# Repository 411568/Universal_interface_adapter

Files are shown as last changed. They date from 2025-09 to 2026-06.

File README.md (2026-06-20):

# Universal Interface Adapter

> **One board. Every interface.**
>
> An open-source industrial communication and I/O platform for embedded development, automation, diagnostics, and rapid prototyping.

Board Image

---

# Universal Interface Adapter

The Universal Interface Adapter (UIA) is a compact, open-source hardware platform designed to bridge embedded systems with industrial and legacy communication interfaces.

Built around an STM32F446 microcontroller, the board combines communication buses, isolated digital inputs, relay outputs, MOSFET drivers, analog I/O, and general-purpose digital interfaces into a single development and integration platform.

Whether you're developing firmware, interfacing with industrial equipment, creating automated test fixtures, or experimenting with communication protocols, the Universal Interface Adapter provides all the essential interfaces on one board.

---

# Features

## Processing

* STM32F446VET6 ARM Cortex-M4 microcontroller
* Up to 180 MHz operation
* USB Full-Speed support
* Rich peripheral set for communication and control applications
* ST-Link programming and debugging interface

---

## Communication Interfaces

### CAN Bus

* Differential CAN transceiver
* Suitable for:

  * Automotive applications
  * Robotics
  * Industrial automation
  * Battery management systems
  * Motor controllers

### RS-232

* Legacy serial communication support
* Compatible with instrumentation and industrial equipment

### RS-422 / RS-485

* Differential long-distance communication
* Multi-drop network capability
* Industrial noise immunity
* Direction control handled by firmware

### UART

* Standard serial communication interface
* Ideal for microcontroller communication and debugging

### I²C

* Sensor and peripheral communication
* EEPROMs
* ADCs and DACs
* Environmental sensors

### SPI

* High-speed peripheral communication
* Displays
* Memory devices
* Data converters
* High-speed sensors

---

## Digital Inputs

### 3x Isolated Inputs

Galvanically isolated inputs designed for industrial environments.

Features:

* Ground loop protection
* Improved noise immunity
* Safe connection to external equipment
* PLC and sensor compatibility

Applications:

* Machine monitoring
* Industrial sensors
* Switch inputs
* Process control systems

---

## Output Interfaces

### 2x Relay Outputs

Integrated relay outputs for switching external devices.

Applications:

* Equipment control
* Power switching
* Automation systems
* Test fixtures
* Safety interlocks

---

### 4x MOSFET Outputs

Low-side MOSFET drivers for directly controlling external loads.

Applications:

* Solenoids
* LEDs
* Small motors
* Relays
* Indicators
* Custom automation systems

---

## General Purpose I/O

### 4x GPIO Channels

Flexible digital I/O for:

* External sensors
* Logic interfacing
* Prototyping
* Custom expansion hardware
* Embedded development

---

## Analog Interfaces

### Analog Inputs

Dedicated analog channels allow direct connection to sensors and measurement circuits.

Applications:

* Temperature sensors
* Voltage monitoring
* Current sensing
* Industrial transmitters
* Data acquisition

### Analog Output

Single analog output channel suitable for:

* Control signals
* Reference voltages
* External instrumentation
* Test equipment

---

## User Interface

### Status LEDs

Four onboard LEDs provide:

* System status indication
* Communication activity indicators
* Diagnostic information
* Application-defined signaling

---

## USB Connectivity

* USB Type-C connector
* USB Full-Speed device interface
* Virtual COM applications
* Firmware updates
* Data logging
* PC connectivity

---

# Hardware Architecture

The board is organized into dedicated functional blocks:

```
USB-C
   │
STM32F446VET6
   ├── CAN Interface
   ├── RS-232 Interface
   ├── RS-422 Interface
   ├── RS-485 Interface
   ├── UART Interfaces
   ├── I²C Interfaces
   ├── SPI Interfaces
   ├── Isolated Inputs
   ├── Relay Outputs
   ├── MOSFET Outputs
   ├── Analog Inputs
   ├── Analog Output
   ├── GPIO Expansion
   └── Status LEDs
```

---

# Firmware

The firmware is written in C and follows a modular architecture that separates hardware drivers from communication protocols and application logic.

## Firmware Responsibilities

### System Initialization

* Clock configuration
* Peripheral initialization
* Interface configuration
* Self-test routines

### Communication Services

* CAN message handling
* RS-232 communication
* RS-422 communication
* RS-485 communication
* USB communication
* UART bridging
* I²C transactions
* SPI transactions

### I/O Services

* Digital input monitoring
* Relay control
* MOSFET output control
* Analog acquisition
* GPIO management

### Application Layer

* Command parser
* Protocol routing
* Event handling
* Diagnostics
* Future protocol extensions

---

# Repository Structure

```
Universal_interface_adapter/
├── firmware/          Firmware source code
├── bom/               Bill of Materials
├── production/        Manufacturing files
├── libs/              Custom KiCad libraries
├── *.kicad_sch        Schematics
├── *.kicad_pcb        PCB layout
├── *.step             3D model
└── schematic_pdf.pdf  Complete schematic documentation
```

---

# Applications

## Industrial Automation

* PLC integration
* Factory diagnostics
* Equipment monitoring
* Protocol conversion

## Embedded Development

* Firmware development
* Hardware bring-up
* Peripheral testing
* Prototyping

## Automotive Development

* CAN experimentation
* ECU diagnostics
* Communication gateways

## Automated Test Systems

* Manufacturing fixtures
* Hardware-in-the-loop testing
* Sensor validation
* Production diagnostics

## Education

* Embedded systems laboratories
* Industrial communication training
* Electronics courses
* Protocol experimentation

---

# Open Hardware

This project is fully open source.

Included in this repository:

* Complete KiCad project
* Schematics
* PCB layout
* Manufacturing files
* Bill of Materials
* Firmware source code
* 3D STEP model

Users are encouraged to study, modify, and extend the design.

---

# Future Commercial Availability

The Universal Interface Adapter is currently under active development.

Planned future offerings:

* Fully assembled and tested boards
* Pre-programmed firmware
* Documentation and example projects
* PC configuration software
* Protocol bridge applications
* Optional enclosure kit
* Long-term firmware support

---

# Vision

The goal of the Universal Interface Adapter is simple:

**Provide developers and engineers with a single board capable of interfacing with nearly every common industrial and embedded communication standard without requiring multiple adapters or development platforms.**

**One board. Multiple protocols. Unlimited possibilities.**

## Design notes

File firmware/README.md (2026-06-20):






# Universal Interface Adapter Firmware

Firmware for the **Universal Interface Adapter (UIA)**, an open-source industrial communication and I/O platform built around the **STM32F446VET6** microcontroller.

The firmware is written entirely in **Rust** and follows a modular architecture designed for reliability, maintainability, and community-driven development.

---

# Philosophy

The goal of this firmware is simple:

> Make industrial and embedded interfaces easy to access, easy to understand, and easy to extend.

Every hardware feature on the board is exposed through a common command-line interface (CLI) over USB, making the board useful as:

* Development platform
* Hardware test tool
* Protocol analyzer
* Automation controller
* Educational platform
* Rapid prototyping tool

---

# Features

## USB CDC Command Interface

The board enumerates as a USB CDC-ACM serial device and provides an interactive CLI.

No special drivers are required on Linux and macOS. Windows typically uses the standard USB serial driver.

Example:

```text
$ screen /dev/ttyACM0 115200
UIA>
```

---

## Supported Interfaces

### Digital Outputs

* 4x MOSFET outputs
* 2x Relay outputs

### Digital Inputs

* 3x Isolated inputs
* 4x GPIO channels

### Analog Interfaces

* 2x Analog inputs (ADC)
* 1x Analog output (DAC)

### Serial Interfaces

* UART
* RS-232
* RS-422
* CAN
* I²C
* SPI

### User Interface

* 4x Status LEDs
* USB command interface

---

# Firmware Architecture

The firmware intentionally separates hardware initialization, drivers, and command handling.

```text
main.rs
│
├── Peripheral Initialization
│   ├── GPIO
│   ├── ADC / DAC
│   ├── UART
│   ├── RS232
│   ├── RS422
│   ├── I²C
│   ├── SPI
│   ├── CAN
│   └── USB
│
├── Command Registry
│   ├── LED Commands
│   ├── MOSFET Commands
│   ├── Relay Commands
│   ├── GPIO Commands
│   ├── Analog Commands
│   ├── Serial Commands
│   └── Interface Commands
│
└── CLI Event Loop
```

The command registry allows new functionality to be added without modifying the main application loop.

---

# Project Structure

```text
firmware/
├── src/
│   ├── main.rs
│   ├── cli/
│   │   ├── mod.rs
│   │   └── commands/
│   └── io_interface/
├── Cargo.toml
├── memory.x
└── README.md
```

---

# Current Command Modules

The firmware currently implements command handlers for:

* Echo
* Setup
* LEDs
* MOSFET outputs
* Relays
* Isolated inputs
* GPIO
* UART
* RS-232
* RS-422
* Analog I/O
* I²C
* SPI
* CAN

Each module is responsible for:

1. Hardware initialization
2. Runtime control
3. CLI integration
4. Error handling

---

# Building

## Requirements

* Rust stable toolchain
* rustup
* cargo
* ARM target support

Install the target:

```bash
rustup target add thumbv7em-none-eabihf
```

---

## Build

```bash
cargo build --release
```

---

## Flash

Example using probe-rs:

```bash
cargo install probe-rs-tools

probe-rs download \
    --chip STM32F446VETx \
    target/thumbv7em-none-eabihf/release/universal_interface_adapter
```

---

# Example CLI Usage

```text
UIA> led on 1
UIA> relay on 2
UIA> mosfet off 3
UIA> gpio read 1
UIA> adc read 0
UIA> i2c scan
UIA> can send 123 DEADBEEF
```

---

# Adding New Commands

The firmware was intentionally designed to make adding features straightforward.

Typical steps:

### 1. Create a command

```rust
pub struct MyCommand;

impl MyCommand {
    pub fn new() -> Self {
        Self
    }
}
```

### 2. Implement the command trait

```rust
impl Command for MyCommand {
    // implementation
}
```

### 3. Register the command

```rust
let _ = registry.register_my_command(MyCommand::new());
```

That's it. The CLI automatically exposes the new functionality.

---

# Why Rust?

Industrial and embedded systems often run continuously and interact with external hardware. Rust provides several advantages:

* Memory safety without garbage collection
* Strong type checking
* Zero-cost abstractions
* Excellent concurrency primitives
* Reduced risk of crashes and undefined behavior
* Maintainable long-term codebase

The objective is to build firmware that is both reliable enough for industrial use and approachable enough for experimentation and learning.

---

# Contributing

Contributions are highly encouraged.

Ideas for future improvements:

* Additional CLI commands
* Protocol bridges
* Configuration storage
* Data logging
* Scriptable command execution
* USB firmware update support
* Modbus support
* CANopen support
* MQTT gateway functionality
* Performance improvements
* Documentation improvements

Pull requests of all sizes are welcome.

If you have an idea, open an issue and let's discuss it.

---

# Development Principles

Please try to keep contributions:

* Modular
* Well documented
* Hardware independent where possible
* Non-blocking
* Safe and idiomatic Rust
* Easy to test and review

---

# Community

This project exists because embedded and industrial development tools should be open, understandable, and hackable.

If you build something interesting with the Universal Interface Adapter, improve the firmware, or add support for new protocols, please submit a pull request.

**Let's build a universal embedded interface platform together.**

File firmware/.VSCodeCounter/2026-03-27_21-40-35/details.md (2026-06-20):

# Details

Date : 2026-03-27 21:40:35

Directory /home/krzysztof/Documents/ELECTRONICS/universal_interface_adapter_board/universal_interface_adapter/firmware

Total : 25 files,  4782 codes, 385 comments, 669 blanks, all 5836 lines

[Summary](results.md) / Details / [Diff Summary](diff.md) / [Diff Details](diff-details.md)

## Files
| filename | language | code | comment | blank | total |
| :--- | :--- | ---: | ---: | ---: | ---: |
| [README.md](/README.md) | Markdown | 45 | 0 | 21 | 66 |
| [build.rs](/build.rs) | Rust | 2 | 0 | 4 | 6 |
| [src/cli/cli\_config.rs](/src/cli/cli_config.rs) | Rust | 69 | 19 | 15 | 103 |
| [src/cli/cli\_loop.rs](/src/cli/cli_loop.rs) | Rust | 99 | 19 | 15 | 133 |
| [src/cli/command.rs](/src/cli/command.rs) | Rust | 9 | 11 | 5 | 25 |
| [src/cli/commands/analog.rs](/src/cli/commands/analog.rs) | Rust | 476 | 27 | 61 | 564 |
| [src/cli/commands/can.rs](/src/cli/commands/can.rs) | Rust | 485 | 26 | 65 | 576 |
| [src/cli/commands/clear.rs](/src/cli/commands/clear.rs) | Rust | 29 | 9 | 9 | 47 |
| [src/cli/commands/echo.rs](/src/cli/commands/echo.rs) | Rust | 48 | 10 | 8 | 66 |
| [src/cli/commands/gpios.rs](/src/cli/commands/gpios.rs) | Rust | 297 | 31 | 39 | 367 |
| [src/cli/commands/i2c.rs](/src/cli/commands/i2c.rs) | Rust | 447 | 16 | 51 | 514 |
| [src/cli/commands/isolated\_inputs.rs](/src/cli/commands/isolated_inputs.rs) | Rust | 120 | 8 | 17 | 145 |
| [src/cli/commands/led.rs](/src/cli/commands/led.rs) | Rust | 141 | 10 | 19 | 170 |
| [src/cli/commands/mod.rs](/src/cli/commands/mod.rs) | Rust | 220 | 65 | 47 | 332 |
| [src/cli/commands/mosfets.rs](/src/cli/commands/mosfets.rs) | Rust | 141 | 10 | 19 | 170 |
| [src/cli/commands/relays.rs](/src/cli/commands/relays.rs) | Rust | 129 | 10 | 19 | 158 |
| [src/cli/commands/rs232.rs](/src/cli/commands/rs232.rs) | Rust | 282 | 2 | 32 | 316 |
| [src/cli/commands/rs422.rs](/src/cli/commands/rs422.rs) | Rust | 322 | 8 | 37 | 367 |
| [src/cli/commands/setup.rs](/src/cli/commands/setup.rs) | Rust | 120 | 15 | 15 | 150 |
| [src/cli/commands/spi.rs](/src/cli/commands/spi.rs) | Rust | 620 | 27 | 72 | 719 |
| [src/cli/commands/uart.rs](/src/cli/commands/uart.rs) | Rust | 397 | 14 | 42 | 453 |
| [src/cli/mod.rs](/src/cli/mod.rs) | Rust | 8 | 0 | 2 | 10 |
| [src/io\_interface/mod.rs](/src/io_interface/mod.rs) | Rust | 1 | 0 | 0 | 1 |
| [src/io\_interface/serial.rs](/src/io_interface/serial.rs) | Rust | 72 | 14 | 13 | 99 |
| [src/main.rs](/src/main.rs) | Rust | 203 | 34 | 42 | 279 |

[Summary](results.md) / Details / [Diff Summary](diff.md) / [Diff Details](diff-details.md)

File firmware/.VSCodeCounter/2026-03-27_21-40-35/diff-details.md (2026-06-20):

# Diff Details

Date : 2026-03-27 21:40:35

Directory /home/krzysztof/Documents/ELECTRONICS/universal_interface_adapter_board/universal_interface_adapter/firmware

Total : 6 files,  2120 codes, 103 comments, 262 blanks, all 2485 lines

[Summary](results.md) / [Details](details.md) / [Diff Summary](diff.md) / Diff Details

## Files
| filename | language | code | comment | blank | total |
| :--- | :--- | ---: | ---: | ---: | ---: |
| [src/cli/commands/analog.rs](/src/cli/commands/analog.rs) | Rust | 476 | 27 | 61 | 564 |
| [src/cli/commands/can.rs](/src/cli/commands/can.rs) | Rust | 485 | 26 | 65 | 576 |
| [src/cli/commands/i2c.rs](/src/cli/commands/i2c.rs) | Rust | 447 | 16 | 51 | 514 |
| [src/cli/commands/mod.rs](/src/cli/commands/mod.rs) | Rust | 25 | 0 | 4 | 29 |
| [src/cli/commands/spi.rs](/src/cli/commands/spi.rs) | Rust | 620 | 27 | 72 | 719 |
| [src/main.rs](/src/main.rs) | Rust | 67 | 7 | 9 | 83 |

[Summary](results.md) / [Details](details.md) / [Diff Summary](diff.md) / Diff Details

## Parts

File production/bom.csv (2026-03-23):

Designator | Footprint | Quantity | Value | LCSC Part #
C1, C2 | 0603 | 2 | 20p
C10, C12 | 1206 | 2 | 2.2u
C11, C13, C15, C16, C17, C18, C3, C41, C5, C6, C7, C9 | 1206 | 12 | 100n
C14 | 1206 | 1 | 1u
C19, C20, C57, C58 | 0805 | 4 | 1u
C21, C24, C25, C26, C28, C29, C30, C31, C34, C35, C36, C37, C38, C39, C8 | 0805 | 15 | 100n
C22, C23, C33 | 0805 | 3 | 10u
C27, C32, C42 | 0805 | 3 | 10n
C4 | 1206 | 1 | 4.7u
C40, C43, C44, C45, C46, C47, C48 | 1206 | 7 | 10u
C49, C50, C51, C52 | 1206 | 4 | 22u
C53, C54, C55, C56 | 0805 | 4 | 22u
D1, D10, D13, D2, D7, D8 | 0805 | 6 | LED_RED
D11, D12, D14, D15, D29, D3, D30, D4, D5, D6, D9 | D_SMA_Handsoldering | 11 | D
D16 | 0805 | 1 | LED_ORANGE
D17 | 0805 | 1 | LED_YELLOW
D18 | 0805 | 1 | LED_GREEN
D19, D20, D21, D22, D23, D24, D25, D26, D27, D28 | D_SMA_Handsoldering | 10 | D_TVS_Small
D31 | D_SMA_Handsoldering | 1 | 35V TVS
D32, D33, D34, D35 | 0805 | 4 | LED GREEN
F1, F2, F3 | 1812 | 3 | RF1406-000
H1, H2, H3, H4 | MountingHole_3mm | 4 | MountingHole
IC1 | SOIC127P1032X265-20N | 1 | ADM3251EARWZ-REEL
J1 | PinHeader_1x08_P2.54mm_Horizontal | 1 | Conn_01x08_Male
J10, J12, J23, J27, J28, J9 | PhoenixContact_MC_1,5_2-G-3.5_1x02_P3.50mm_Horizontal | 6 | Phoenix
J11, J24, J25, J26, J7, J8 | PinHeader_1x02_P2.54mm_Vertical | 6 | Goldpin
J13, J15, J31, J33, J34 | PhoenixContact_MC_1,5_4-G-3.5_1x04_P3.50mm_Horizontal | 5 | Phoenix
J14, J16, J32, J39, J40 | PinHeader_1x04_P2.54mm_Vertical | 5 | Goldpin
J17, J19, J3, J35, J36, J4, J41, J42 | PhoenixContact_MC_1,5_3-G-3.5_1x03_P3.50mm_Horizontal | 8 | Phoenix
J18, J21, J37, J38, J43, J44, J5, J6 | PinHeader_1x03_P2.54mm_Vertical | 8 | Goldpin
J2 | GCT_USB4800-03-A_REVA | 1 | USB4800-03-A_REVA
J20 | PhoenixContact_MC_1,5_5-G-3.5_1x05_P3.50mm_Horizontal | 1 | Phoenix
J22 | PinHeader_1x05_P2.54mm_Vertical | 1 | Goldpin
J29 | PhoenixContact_MC_1,5_2-G-3.5_1x02_P3.50mm_Horizontal | 1 | Conn_01x02
J30 | BarrelJack_GCT_DCJ200-10-A_Horizontal | 1 | Barrel_Jack_Switch
JP1, JP10, JP11, JP12, JP13, JP14, JP15, JP16, JP17, JP18, JP19, JP2, JP20, JP21, JP22, JP3, JP4, JP8, JP9 | PinHeader_1x02_P2.54mm_Vertical | 19 | Jumper
JP5 | PinHeader_1x02_P2.54mm_Vertical | 1 | HS
JP6 | PinHeader_1x02_P2.54mm_Vertical | 1 | LP
JP7 | PinHeader_1x02_P2.54mm_Vertical | 1 | SC
K1, K2 | RELAY_LEG-24 | 2 | LEG-5
Q1, Q2, Q3, Q4, Q5, Q6 | SOT-23 | 6 | IRLML6244
R1, R5, R6 | 1206 | 3 | DNP
R10 | 1206 | 1 | 33k
R11 | 1206 | 1 | 82k
R12, R13, R29, R32, R33, R34, R35 | 0805 | 7 | 1k
R14, R15, R24, R25, R28, R42, R43, R46, R47, R74, R75, R76, R77 | 0805 | 13 | 2.2k
R16, R17, R20, R21, R22, R23, R30, R36, R37, R38, R39, R52, R58, R62, R64, R68, R69, R72, R73 | 0805 | 19 | 10k
R18, R19 | 0805 | 2 | 4.7k
R2, R3 | 1206 | 2 | 20
R26, R27, R31 | 0805 | 3 | 200
R4, R7 | 1206 | 2 | 5.1k
R40, R41, R44, R45 | 0805 | 4 | 100
R48 | 1206 | 1 | 47k
R49, R57 | 1206 | 2 | 120
R50, R51, R53, R54, R79, R80, R81, R82, R83, R84, R85, R86 | 0805 | 12 | 10
R55, R56 | 1206 | 2 | 560
R59 | 0805 | 1 | 30k
R60 | 0805 | 1 | 15k
R61 | 0805 | 1 | 0
R63, R65 | 0805 | 2 | 1.5k
R66, R67 | 0805 | 2 | 3.3k
R70 | 0805 | 1 | 1.37k
R71 | 0805 | 1 | 2.21k
R8, R9 | 1206 | 2 | 10k
SW1 | SW_SPST_TL3342 | 1 | SW_Push
U1 | SOT-23-6 | 1 | USBLC6-2SC6
U10, U11 | CONV_RPX-2.5-R | 2 | RPX-2.5-R
U12 | Converter_DCDC_TRACO_TEA1-xxxx_THT | 1 | TEA1-0505
U2 | LQFP-100_14x14mm_P0.5mm | 1 | STM32F446VETx
U3, U4, U5 | SO-4_4.4x3.6mm_P2.54mm | 3 | LTV-356T
U6 | SOIC-8_3.9x4.9mm_P1.27mm | 1 | SN65HVD230
U7 | VSSOP-8_2.3x2mm_P0.5mm | 1 | TXB0102DCU
U8 | SOIC-20W_7.5x12.8mm_P1.27mm | 1 | ADM2582E
U9 | SOIC-8_3.9x4.9mm_P1.27mm | 1 | OPA197xD
Y1 | Crystal_SMD_HC49-SD | 1 | 8MHz

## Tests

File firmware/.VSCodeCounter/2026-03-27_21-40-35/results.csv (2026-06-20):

filename | "language" | "Rust" | "Markdown" | "comment" | "blank" | "total"
/home/krzysztof/Documents/ELECTRONICS/universal_interface_adapter_board/universal_interface_adapter/firmware/README.md | "Markdown" | 0 | 45 | 0 | 21 | 66
/home/krzysztof/Documents/ELECTRONICS/universal_interface_adapter_board/universal_interface_adapter/firmware/build.rs | "Rust" | 2 | 0 | 0 | 4 | 6
/home/krzysztof/Documents/ELECTRONICS/universal_interface_adapter_board/universal_interface_adapter/firmware/src/cli/cli_config.rs | "Rust" | 69 | 0 | 19 | 15 | 103
/home/krzysztof/Documents/ELECTRONICS/universal_interface_adapter_board/universal_interface_adapter/firmware/src/cli/cli_loop.rs | "Rust" | 99 | 0 | 19 | 15 | 133
/home/krzysztof/Documents/ELECTRONICS/universal_interface_adapter_board/universal_interface_adapter/firmware/src/cli/command.rs | "Rust" | 9 | 0 | 11 | 5 | 25
/home/krzysztof/Documents/ELECTRONICS/universal_interface_adapter_board/universal_interface_adapter/firmware/src/cli/commands/analog.rs | "Rust" | 476 | 0 | 27 | 61 | 564
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

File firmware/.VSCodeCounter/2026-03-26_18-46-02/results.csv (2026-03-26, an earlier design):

filename | "language" | "Rust" | "Markdown" | "comment" | "blank" | "total"
/home/krzysztof/Documents/ELECTRONICS/universal_interface_adapter_board/universal_interface_adapter/firmware/README.md | "Markdown" | 0 | 45 | 0 | 21 | 66
/home/krzysztof/Documents/ELECTRONICS/universal_interface_adapter_board/universal_interface_adapter/firmware/build.rs | "Rust" | 2 | 0 | 0 | 4 | 6
/home/krzysztof/Documents/ELECTRONICS/universal_interface_adapter_board/universal_interface_adapter/firmware/src/cli/cli_config.rs | "Rust" | 69 | 0 | 19 | 15 | 103
/home/krzysztof/Documents/ELECTRONICS/universal_interface_adapter_board/universal_interface_adapter/firmware/src/cli/cli_loop.rs | "Rust" | 99 | 0 | 19 | 15 | 133
/home/krzysztof/Documents/ELECTRONICS/universal_interface_adapter_board/universal_interface_adapter/firmware/src/cli/command.rs | "Rust" | 9 | 0 | 11 | 5 | 25
/home/krzysztof/Documents/ELECTRONICS/universal_interface_adapter_board/universal_interface_adapter/firmware/src/cli/commands/clear.rs | "Rust" | 29 | 0 | 9 | 9 | 47
/home/krzysztof/Documents/ELECTRONICS/universal_interface_adapter_board/universal_interface_adapter/firmware/src/cli/commands/echo.rs | "Rust" | 48 | 0 | 10 | 8 | 66
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

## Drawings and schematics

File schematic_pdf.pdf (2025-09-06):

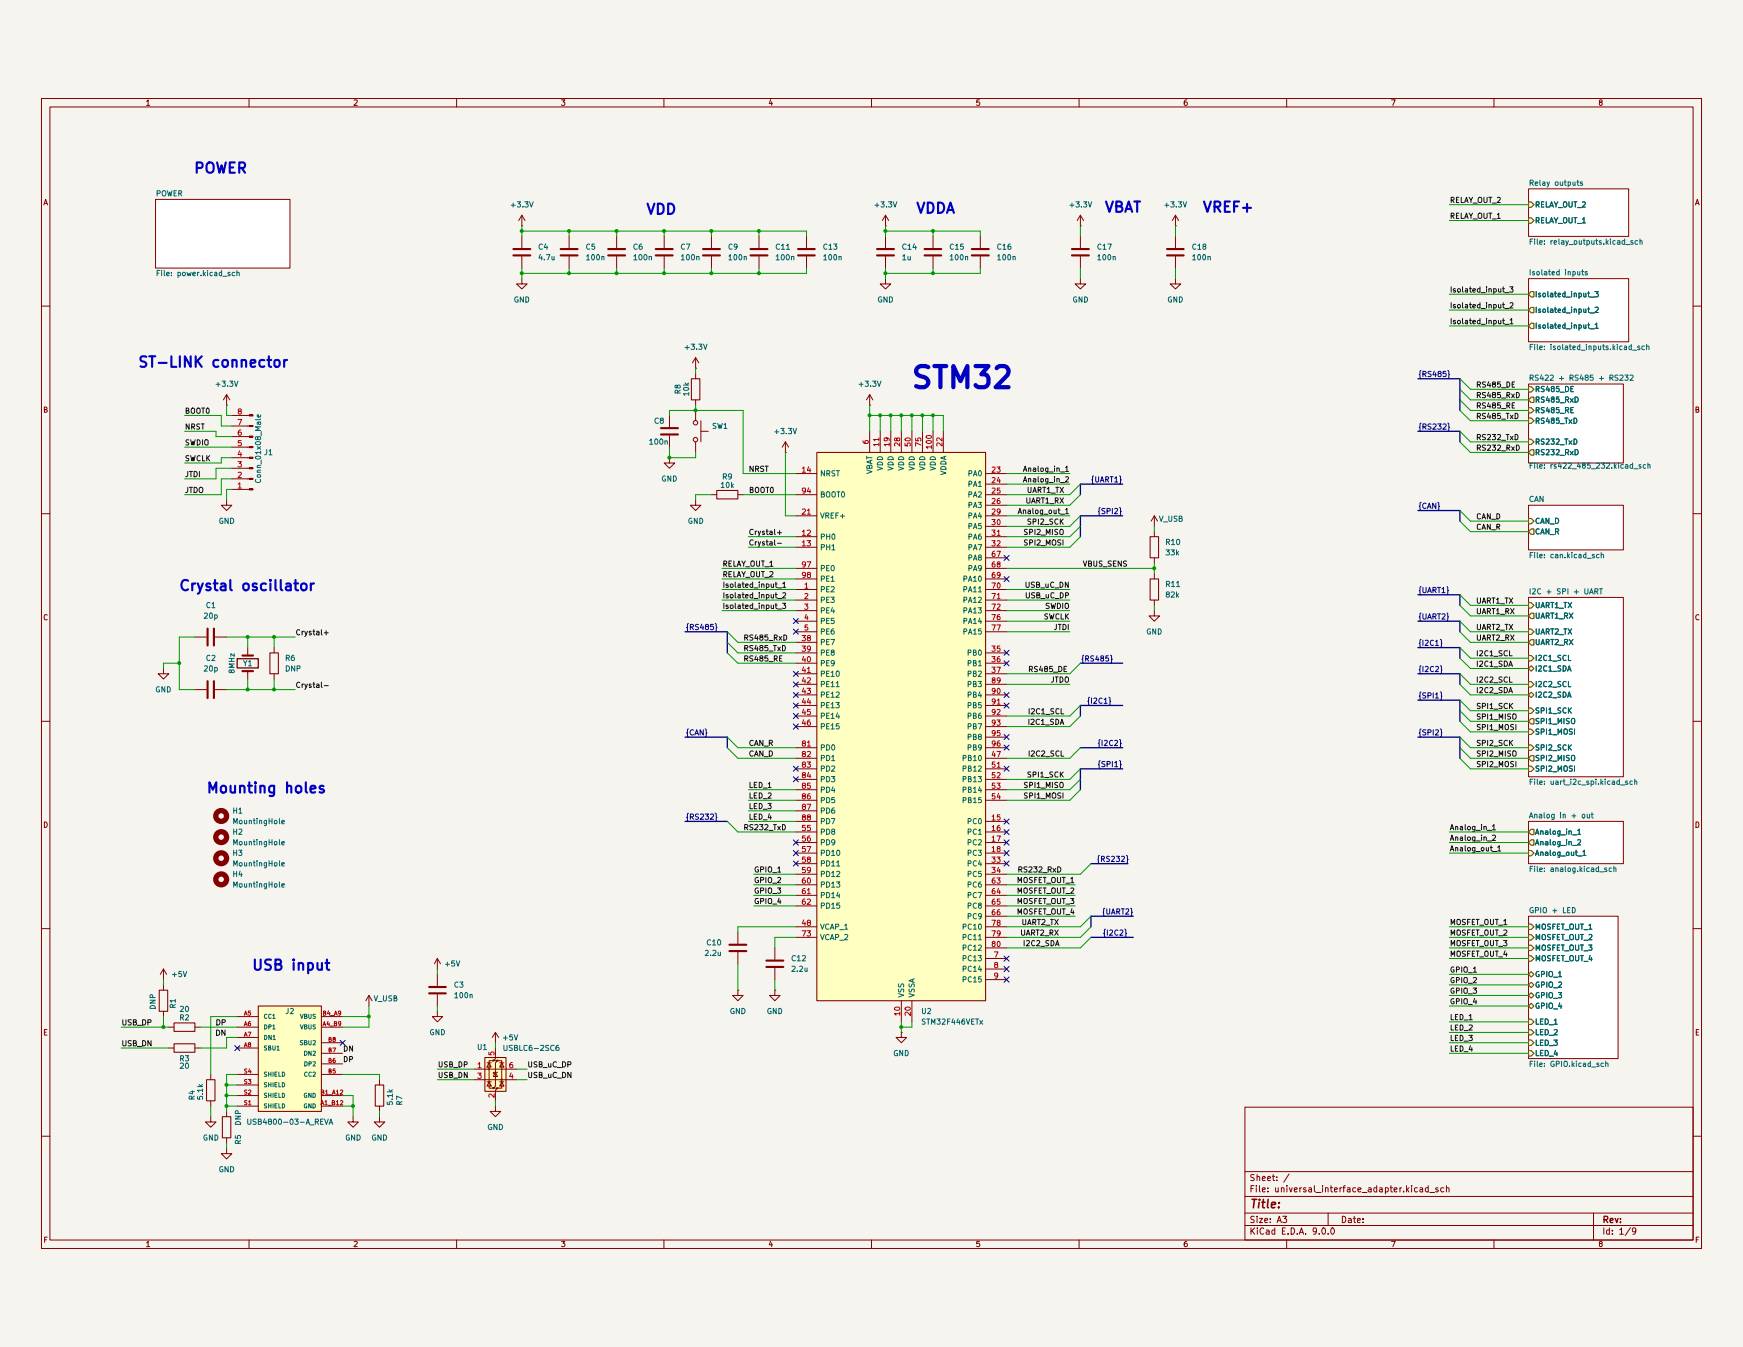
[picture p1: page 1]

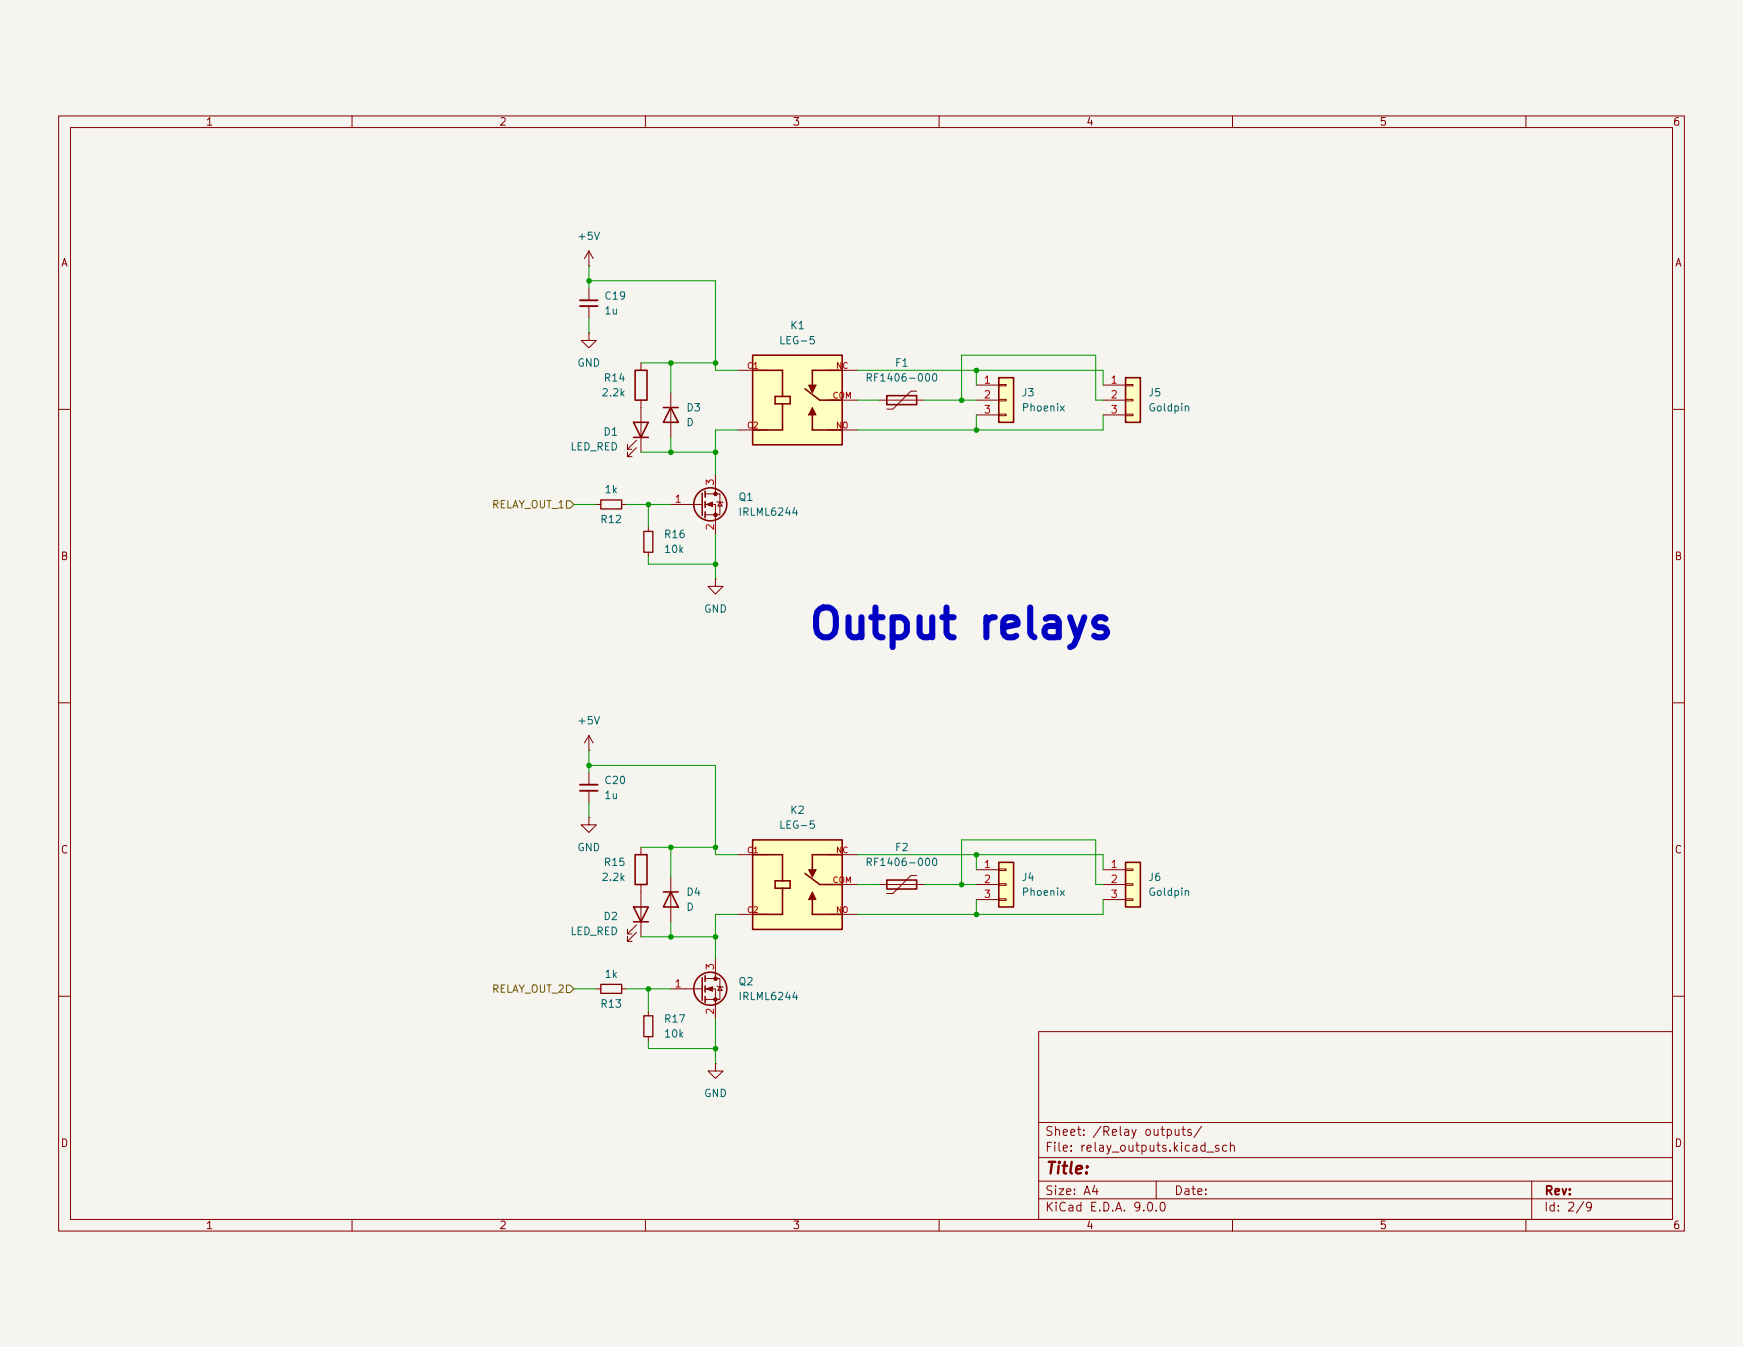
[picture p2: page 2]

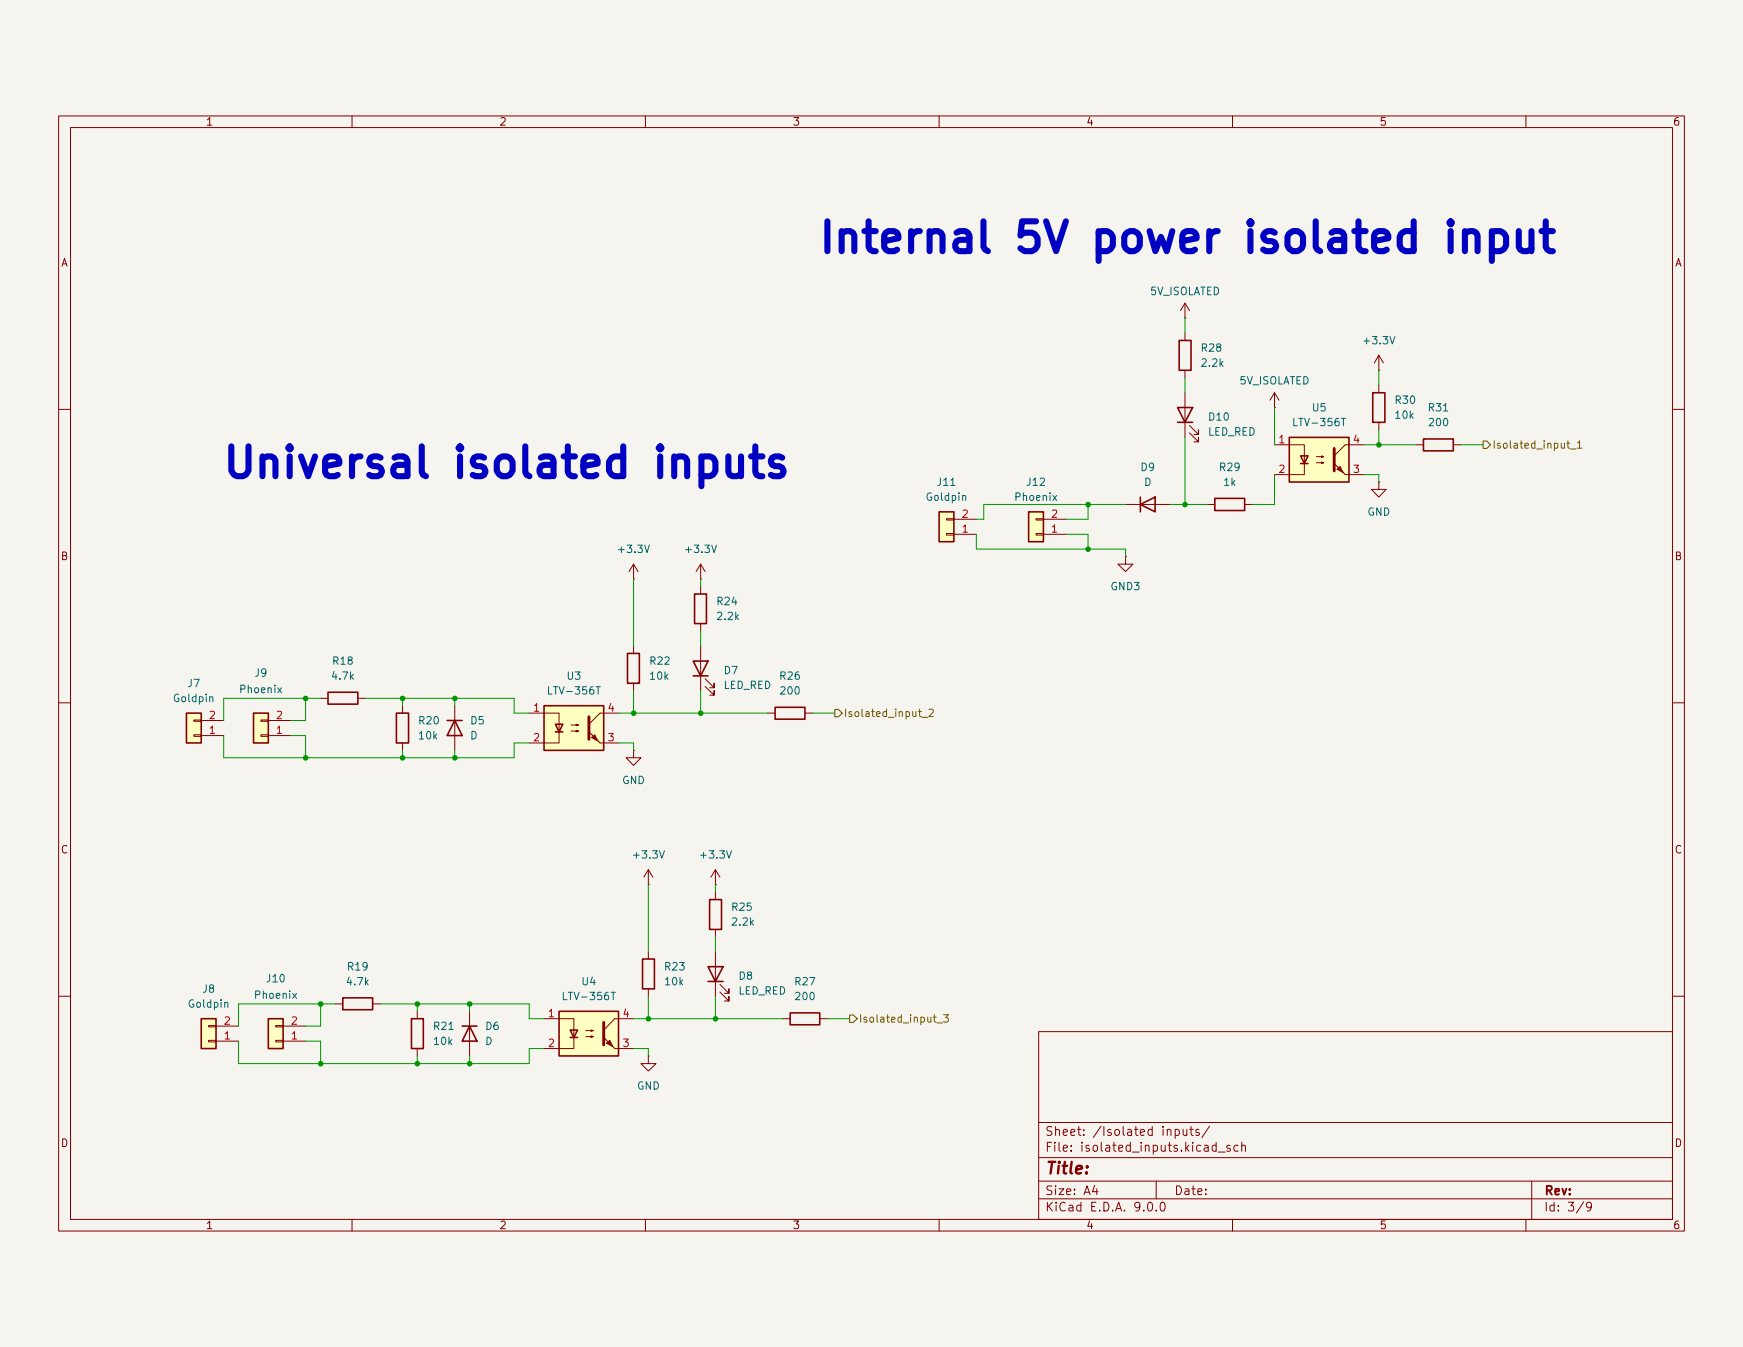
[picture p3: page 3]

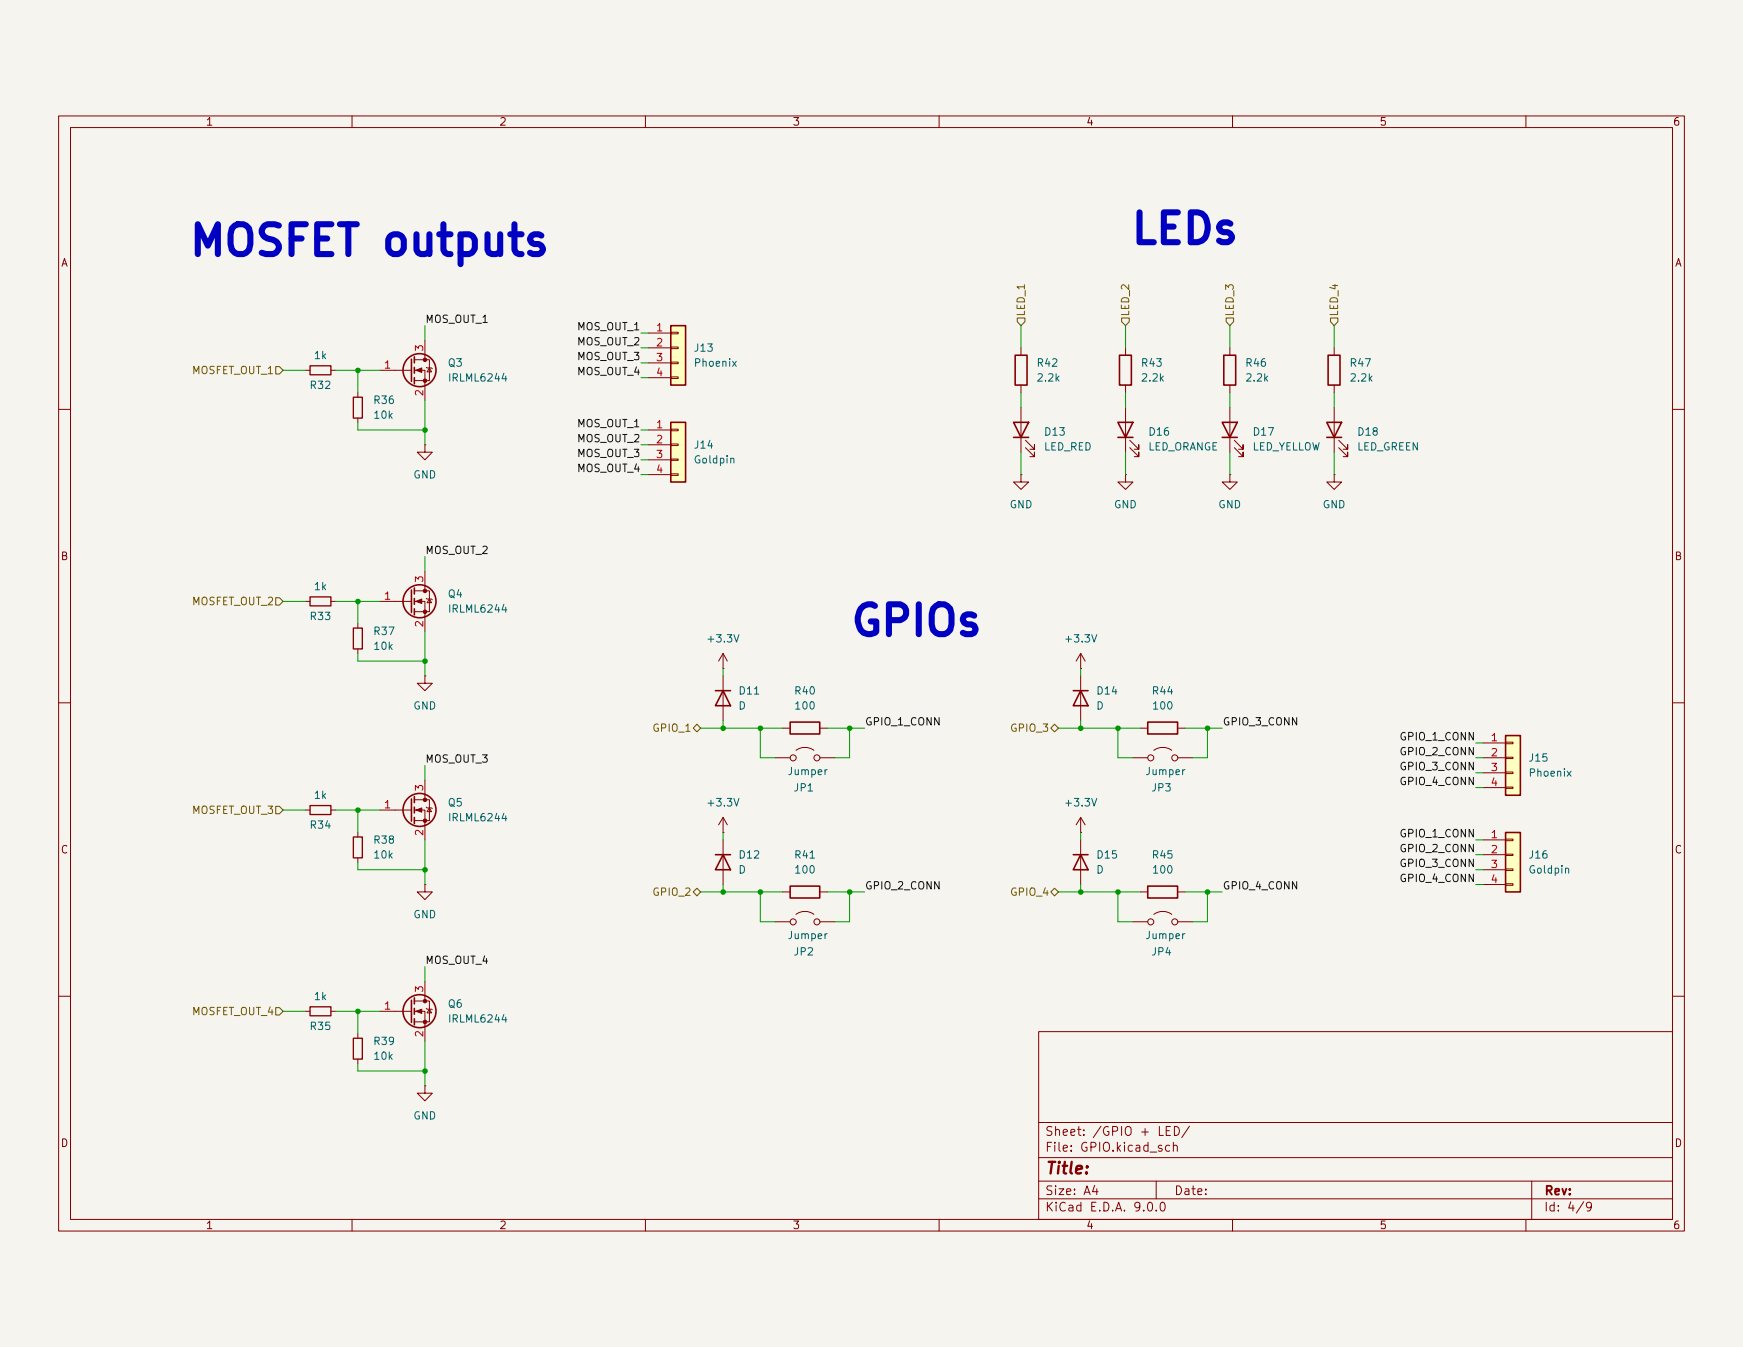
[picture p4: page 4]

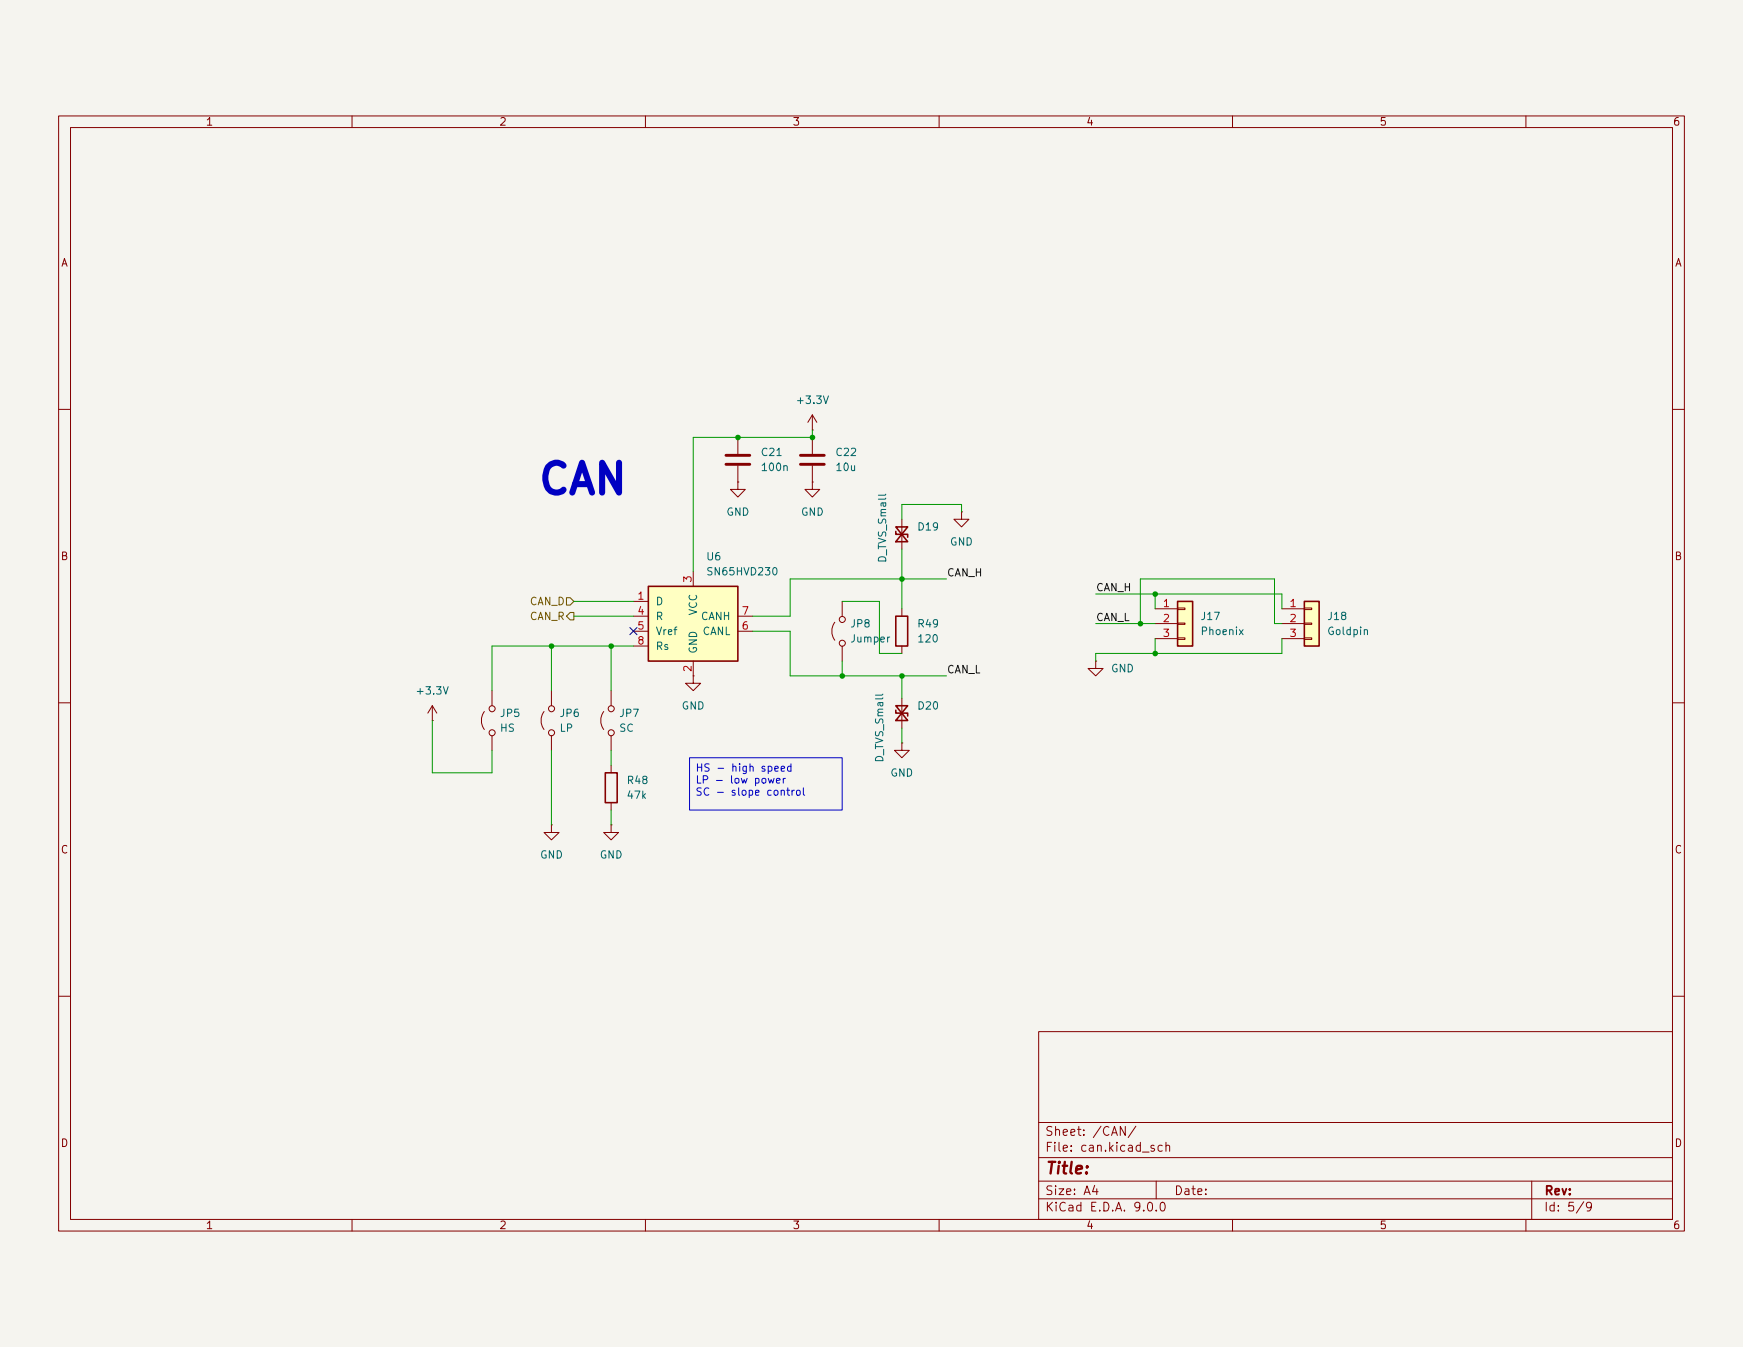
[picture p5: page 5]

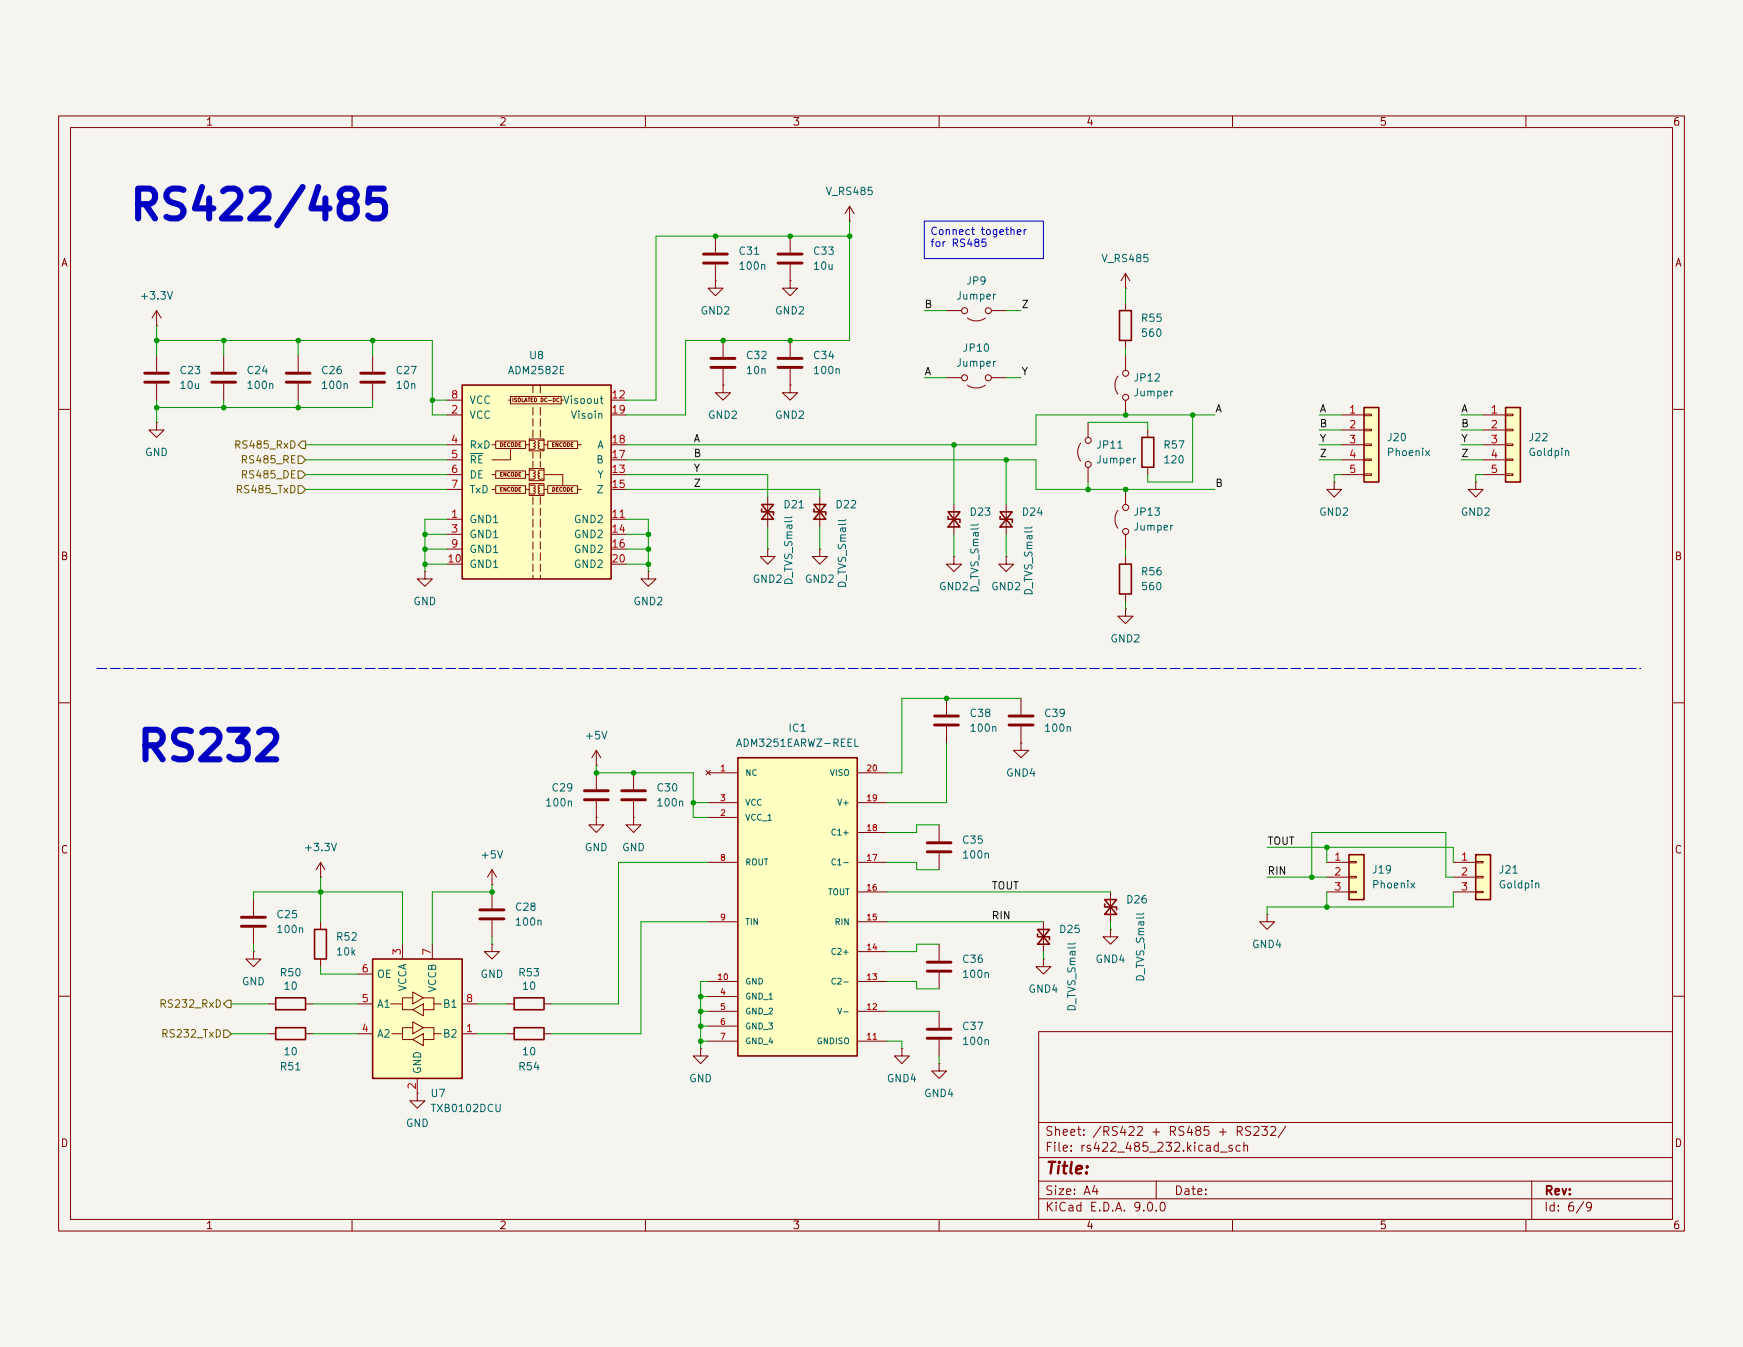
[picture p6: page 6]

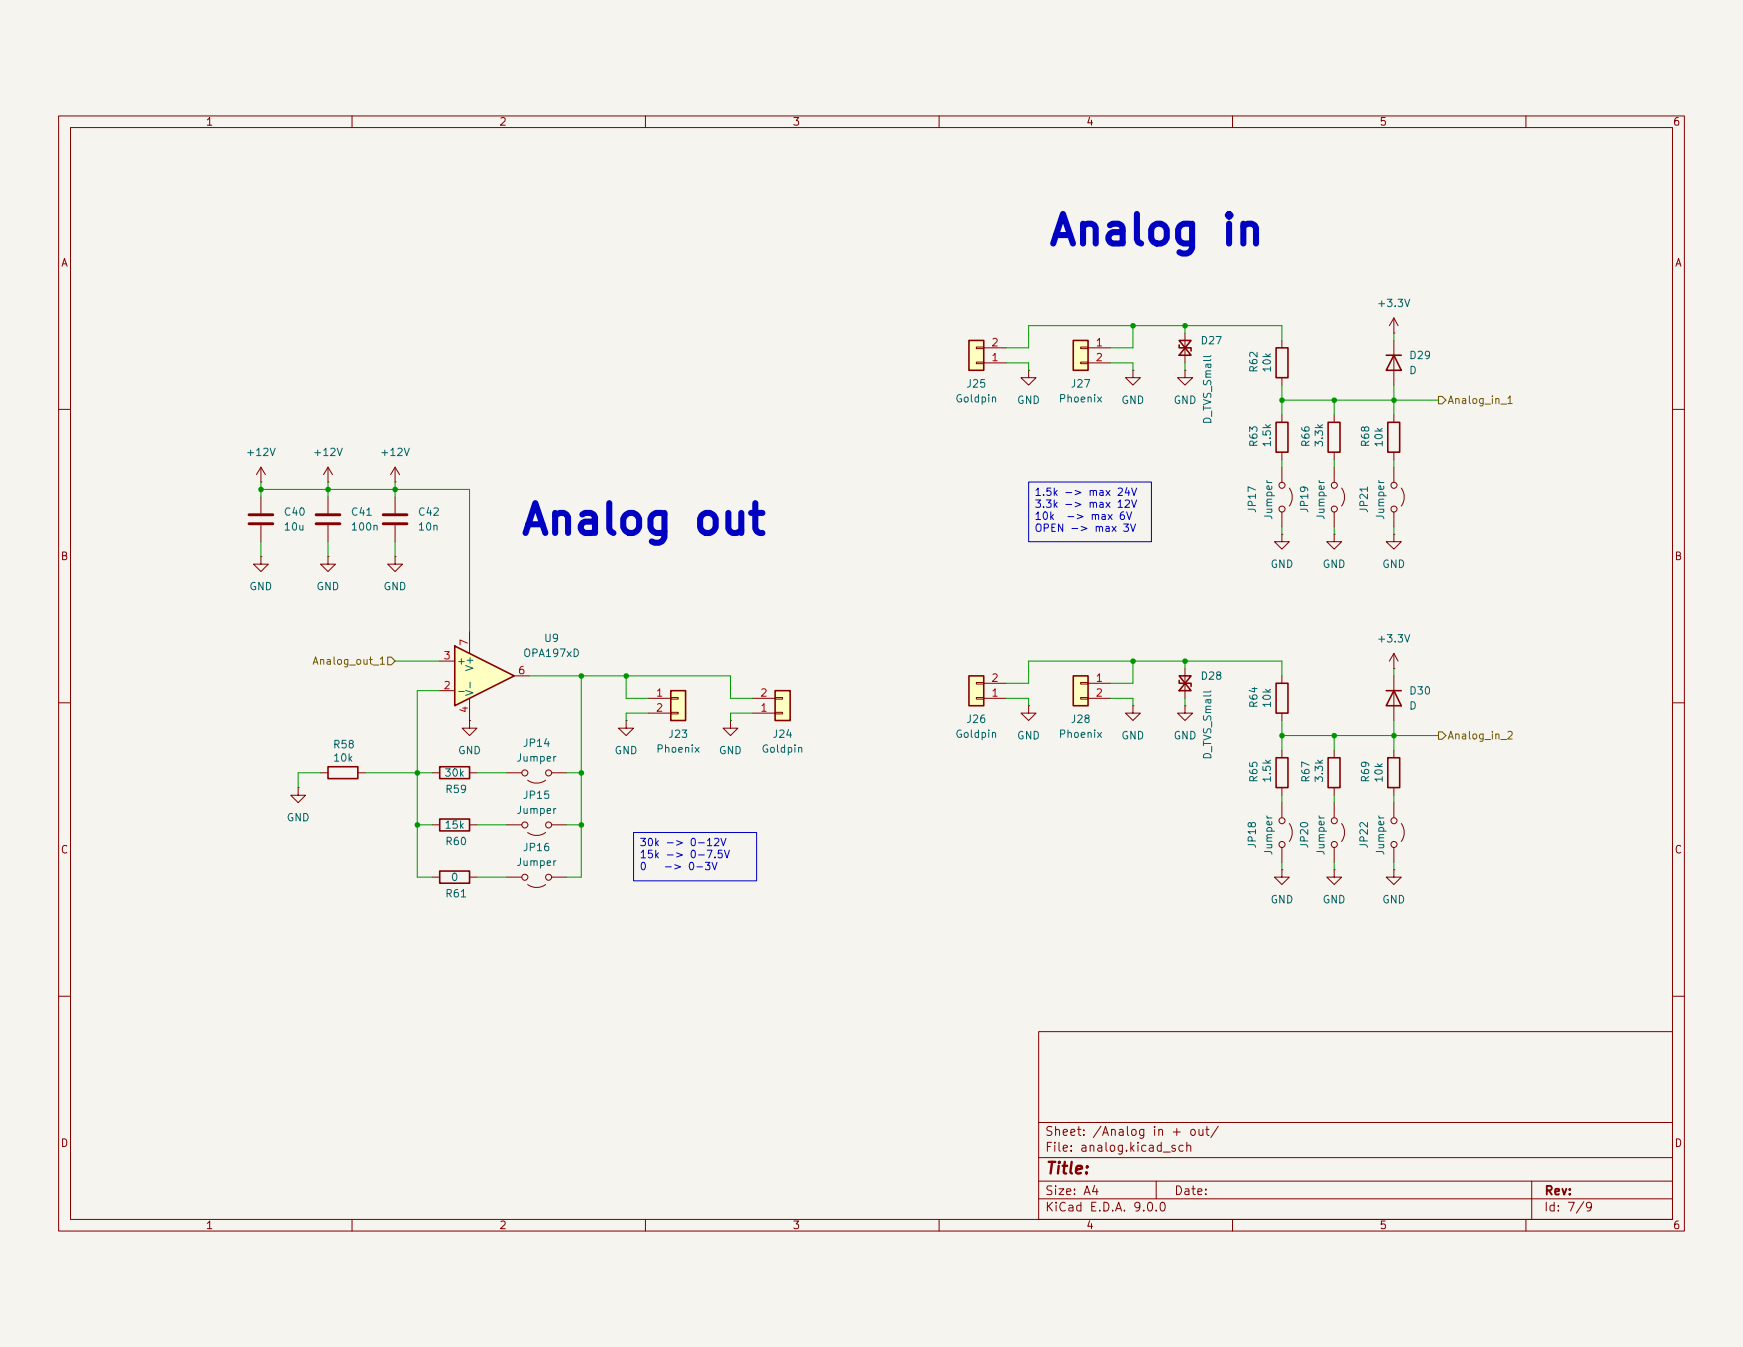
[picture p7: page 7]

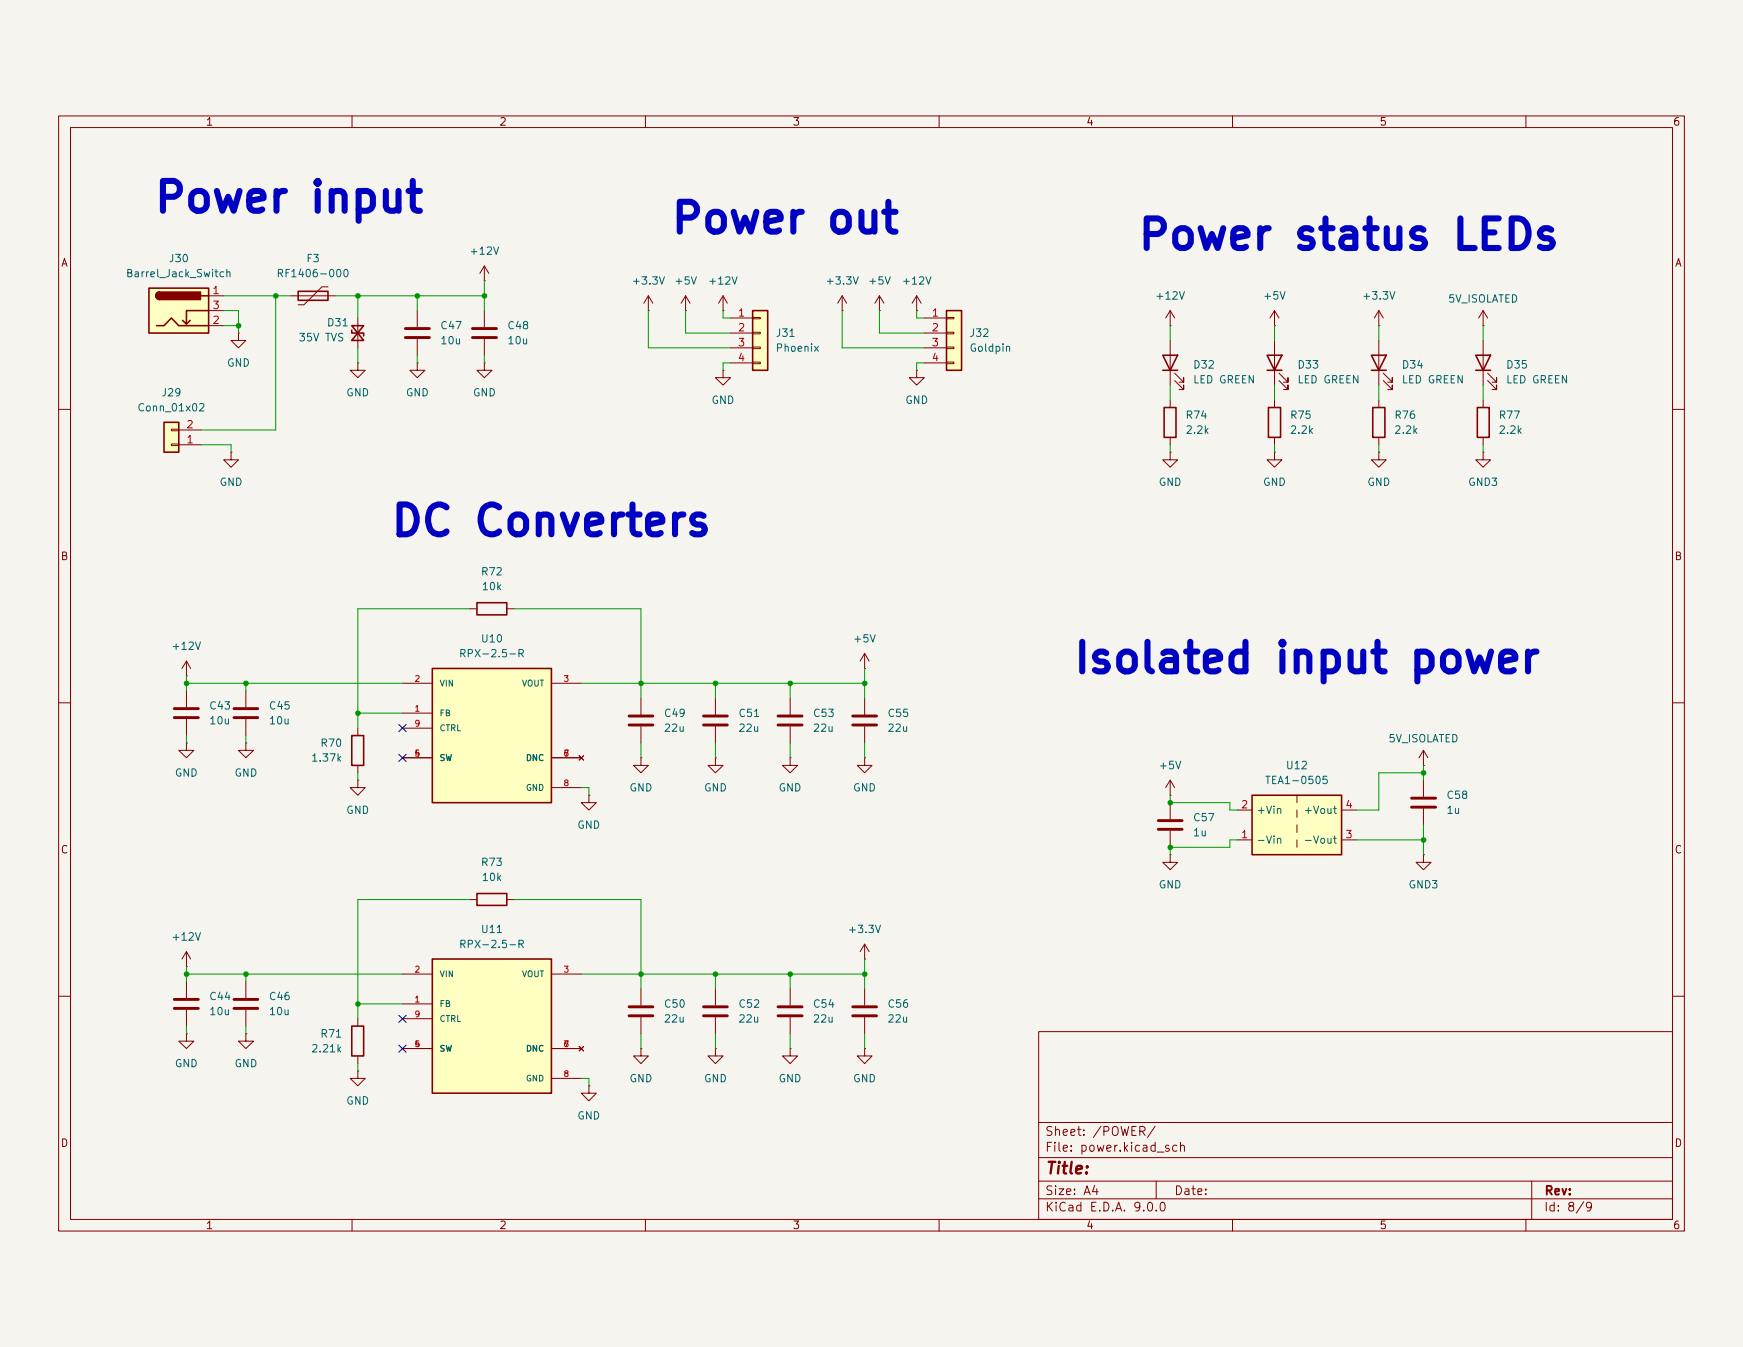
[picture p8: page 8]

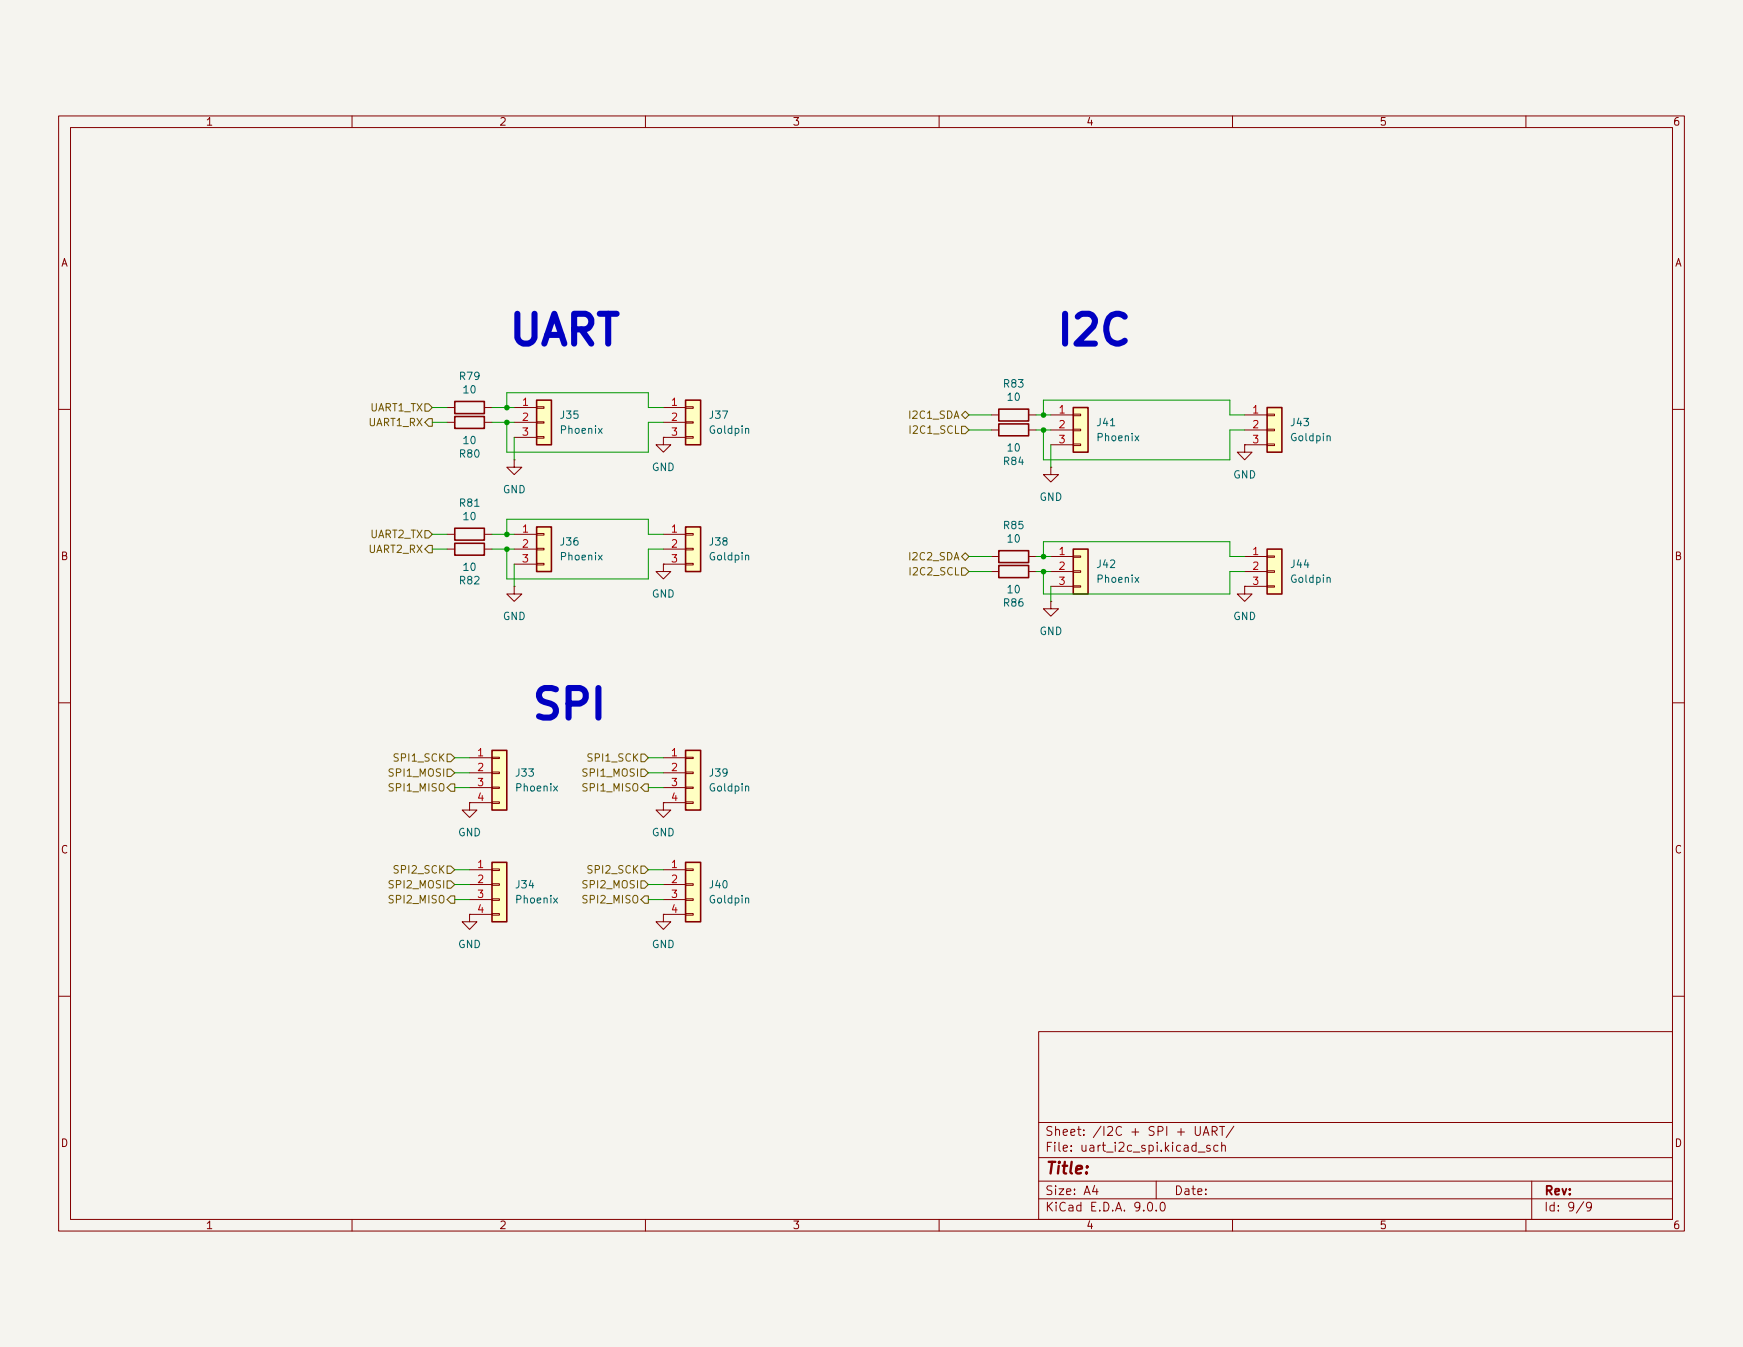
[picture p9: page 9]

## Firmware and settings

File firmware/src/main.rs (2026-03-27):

//! CDC-ACM serial port example with CLI interface
//! Target board: any STM32F4 with a OTG FS peripheral and a 8MHz HSE crystal
#![no_std]
#![no_main]

// #![allow(unused)]  // Allows all unused code in this file
// #![allow(unused_variables)]  // Only allows unused variables
// #![allow(unused_imports)]    // Only allows unused imports
#![allow(dead_code)]         // Only allows unused functions/struct

use panic_halt as _;

use cortex_m_rt::entry;
use static_cell::ConstStaticCell;
use static_cell::StaticCell;
use stm32f4xx_hal::otg_fs::{UsbBus, USB};
use stm32f4xx_hal::rcc::Config;
use stm32f4xx_hal::{pac, prelude::*};
use stm32f4xx_hal::serial;
use stm32f4xx_hal::i2c::I2c;
use stm32f4xx_hal::spi::{Spi, Mode, Phase, Polarity};
use stm32f4xx_hal::can::CanExt;
use stm32f4xx_hal::adc::{Adc, config::AdcConfig};
use stm32f4xx_hal::dac::{dac, DacPin};
use usb_device::prelude::*;
use usb_device::bus::UsbBusAllocator;

mod io_interface;
mod cli;

use io_interface::serial::SerialIO;
use cli::CommandRegistry;
use cli::CliConfig;
use cli::commands::{EchoCommand, ClearCommand, SetupCommand, LedCommand, MosfetCommand, RelayCommand, IsolatedInputCommand, GpioCommand, UartCommand, Rs422Command, Rs232Command, AnalogCommand, I2cCommand, SpiCommand, CanCommand};


// Statically allocate memory for USB endpoint buffers
static EP_MEMORY: ConstStaticCell<[u32; 1024]> = ConstStaticCell::new([0; 1024]);
// Statically allocate memory for the USB bus allocator
static USB_BUS: StaticCell<Option<UsbBusAllocator<UsbBus<USB>>>> = StaticCell::new();


fn initialize_peripherals() -> SerialIO {
    let dp = pac::Peripherals::take().unwrap();
    // let cp = cortex_m::peripheral::Peripherals::take().unwrap();

    // Set the main clock
    let mut rcc = dp
        .RCC
        .freeze(Config::hse(8.MHz()).sysclk(48.MHz()).require_pll48clk());

    // Split the GPIO
    let gpioa = dp.GPIOA.split(&mut rcc);
    let gpiob = dp.GPIOB.split(&mut rcc);
    let gpiod = dp.GPIOD.split(&mut rcc);
    let gpioc = dp.GPIOC.split(&mut rcc);
    let gpioe = dp.GPIOE.split(&mut rcc);

    // Initialize LED pins
    LedCommand::init_pins(
        gpiod.pd4,
        gpiod.pd5,
        gpiod.pd6,
        gpiod.pd7,
    );

    // Initialize the MOSFET pins
    MosfetCommand::init_pins(
        gpioc.pc6,
        gpioc.pc7,
        gpioc.pc8,
        gpioc.pc9,
    );

    // Initialize the Relay pins
    RelayCommand::init_pins(
        gpioe.pe0,
        gpioe.pe1,
    );

    // Initialize the Isolated Input pins
    IsolatedInputCommand::init_pins(
        gpioe.pe2,
        gpioe.pe3,
        gpioe.pe4,
    );

    // Initialize the GPIO pins
    GpioCommand::init_pins(
        gpiod.pd12,
        gpiod.pd13,
        gpiod.pd14,
        gpiod.pd15,
    );

     // Initialize UART1 (USART2) - Example pins PA2/PA3
    let uart1_tx = gpioa.pa2.into_alternate();
    let uart1_rx = gpioa.pa3.into_alternate();
    let uart1 = dp.USART2.serial(
        (uart1_tx, uart1_rx),
        serial::config::Config::default().baudrate(9600.bps()),
        &mut rcc,
    ).unwrap();
    UartCommand::init_uart1(uart1);

    // Initialize UART2 (UART4) - Example pins PC10/PC11
    let uart2_tx = gpioc.pc10.into_alternate(); 
    let uart2_rx = gpioc.pc11.into_alternate(); 
    let uart2 = dp.UART4.serial(
        (uart2_tx, uart2_rx),
        serial::config::Config::default().baudrate(9600.bps()),
        &mut rcc,
    ).unwrap();
    UartCommand::init_uart2(uart2);

    // Initialize RS422 (USART1) with control pins
    let rs422_tx = gpioe.pe8.into_alternate();
    let rs422_rx = gpioe.pe7.into_alternate();
    let rs422_re = gpioe.pe9.into_push_pull_output(); // RE pin (active LOW)
    let rs422_de = gpiob.pb2.into_push_pull_output(); // DE pin (active HIGH)
    let rs422 = dp.UART5.serial(
        (rs422_tx, rs422_rx),
        serial::config::Config::default().baudrate(9600.bps()),
        &mut rcc,
    ).unwrap();
    Rs422Command::init(rs422, rs422_re, rs422_de);

    // Initialize RS232 (UART4)
    let rs232_tx = gpiod.pd8.into_alternate();
    let rs232_rx = gpioc.pc5.into_alternate();
    let rs232 = dp.USART3.serial(
        (rs232_tx, rs232_rx),
        serial::config::Config::default().baudrate(9600.bps()),
        &mut rcc,
    ).unwrap();
    Rs232Command::init(rs232);

    // Initialize ADC and DAC for analog operations
    let adc_config = AdcConfig::default();
    let adc = Adc::new(dp.ADC1, true, adc_config, &mut rcc);
    let adc_pin1 = gpioa.pa0.into_analog();
    let adc_pin2 = gpioa.pa1.into_analog();
    
    // Initialize DAC - PA4 is DAC channel 1
    let dac_pin = gpioa.pa4.into_analog();
    let mut dac_ch1 = dac(dp.DAC, dac_pin, &mut rcc);
    dac_ch1.enable();
    
    AnalogCommand::init(adc, adc_pin1, adc_pin2, dac_ch1);

    // Initialize I2C1 - PB6 (SCL), PB7 (SDA)
    let i2c1_scl = gpiob.pb6.into_alternate_open_drain();
    let i2c1_sda = gpiob.pb7.into_alternate_open_drain();
    let i2c1 = I2c::new(
        dp.I2C1,
        (i2c1_scl, i2c1_sda),
        100.kHz(),
        &mut rcc,
    );
    I2cCommand::init_i2c1(i2c1);

    // Initialize I2C2 - PB10 (SCL), PC12 (SDA)
    let i2c2_scl = gpiob.pb10.into_alternate_open_drain();
    let i2c2_sda = gpioc.pc12.into_alternate_open_drain();
    let i2c2 = I2c::new(
        dp.I2C2,
        (i2c2_scl, i2c2_sda),
        100.kHz(),
        &mut rcc,
    );
    I2cCommand::init_i2c2(i2c2);

    // Initialize SPI1 (labeled as SPI 2 in documentation) - PA5 (SCK), PA6 (MISO), PA7 (MOSI)
    let spi1_sck = gpioa.pa5.into_alternate();
    let spi1_miso = gpioa.pa6.into_alternate();
    let spi1_mosi = gpioa.pa7.into_alternate();
    let spi1 = Spi::new(
        dp.SPI1,
        (Some(spi1_sck), Some(spi1_miso), Some(spi1_mosi)),
        Mode {
            polarity: Polarity::IdleLow,
            phase: Phase::CaptureOnFirstTransition,
        },
        1.MHz(),
        &mut rcc,
    );
    SpiCommand::init_spi1(spi1);

    // Initialize SPI2 (labeled as SPI 1 in documentation) - PB13 (SCK), PB14 (MISO), PB15 (MOSI)
    let spi2_sck = gpiob.pb13.into_alternate();
    let spi2_miso = gpiob.pb14.into_alternate();
    let spi2_mosi = gpiob.pb15.into_alternate();
    let spi2 = Spi::new(
        dp.SPI2,
        (Some(spi2_sck), Some(spi2_miso), Some(spi2_mosi)),
        Mode {
            polarity: Polarity::IdleLow,
            phase: Phase::CaptureOnFirstTransition,
        },
        1.MHz(),
        &mut rcc,
    );
    SpiCommand::init_spi2(spi2);

    // Initialize CAN1 (PD0 = CAN_RX, PD1 = CAN_TX)
    let can_rx = gpiod.pd0.into_alternate();
    let can_tx = gpiod.pd1.into_alternate();
    
    let can1 = dp.CAN1.can((can_tx, can_rx), &mut rcc);
    CanCommand::init_can(can1);

    // Create the USB device
    let usb = USB::new(
        (dp.OTG_FS_GLOBAL, dp.OTG_FS_DEVICE, dp.OTG_FS_PWRCLK),
        (gpioa.pa11, gpioa.pa12),
        &rcc.clocks,
    );

    // Store the USB bus allocator
    let usb_bus = USB_BUS.init(Some(UsbBus::new(usb, EP_MEMORY.take())));
    let usb_bus = usb_bus.as_ref().unwrap();

    let serial = usbd_serial::SerialPort::new(usb_bus);

    let usb_dev = UsbDeviceBuilder::new(usb_bus, UsbVidPid(0x16c0, 0x27dd))
        .device_class(usbd_serial::USB_CLASS_CDC)
        .strings(&[StringDescriptors::default()
            .manufacturer("Boards & Bits")
            .product("Universal Interface Adapter v1.0")
            .serial_number("v1.0")])
        .unwrap()
        .build();

    SerialIO::new(serial, usb_dev)
}



#[entry]
fn main() -> ! {
    // Initialize serial interface (also sets up LEDs)
    let mut serial_io = initialize_peripherals();
    
    // Small delay for USB enumeration
    for _ in 0..100_000 {
        cortex_m::asm::nop();
    }

    // Create command registry
    let mut registry = CommandRegistry::new();
    let mut config = CliConfig::new(); 
    
    // Create and register commands
    let _ = registry.register_echo(EchoCommand::new());
    let _ = registry.register_setup(SetupCommand::new());
    let _ = registry.register_clear(ClearCommand::new());
    let _ = registry.register_led(LedCommand::new());
    let _ = registry.register_mosfets(MosfetCommand::new());
    let _ = registry.register_relays(RelayCommand::new());
    let _ = registry.register_isolated_inputs(IsolatedInputCommand::new());
    let _ = registry.register_gpios(GpioCommand::new());
    let _ = registry.register_uart(UartCommand::new());
    let _ = registry.register_rs422(Rs422Command::new());
    let _ = registry.register_rs232(Rs232Command::new());
    let _ = registry.register_analog(AnalogCommand::new());
    let _ = registry.register_i2c(I2cCommand::new());
    let _ = registry.register_spi(SpiCommand::new());
    let _ = registry.register_can(CanCommand::new());

    // Initialize all commands
    if let Err(e) = registry.initialize_all_commands() {
        let _ = serial_io.write_str("Initialization error: ");
        let _ = serial_io.write_str(e);
        let _ = serial_io.write_str("\r\n");
    }

    // Start CLI loop
    cli::run_cli(&mut serial_io, &mut registry, &mut config);
}

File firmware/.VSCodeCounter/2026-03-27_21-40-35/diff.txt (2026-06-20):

Date : 2026-03-27 21:40:35
Directory : /home/krzysztof/Documents/ELECTRONICS/universal_interface_adapter_board/universal_interface_adapter/firmware
Total : 6 files,  2120 codes, 103 comments, 262 blanks, all 2485 lines

Languages
+----------+------------+------------+------------+------------+------------+
| language | files      | code       | comment    | blank      | total      |
+----------+------------+------------+------------+------------+------------+
| Rust     |          6 |      2,120 |        103 |        262 |      2,485 |
+----------+------------+------------+------------+------------+------------+

Directories
+-----------------------------------------------------------------------------------------------------------------------------------------+------------+------------+------------+------------+------------+
| path                                                                                                                                    | files      | code       | comment    | blank      | total      |
+-----------------------------------------------------------------------------------------------------------------------------------------+------------+------------+------------+------------+------------+
| .                                                                                                                                       |          6 |      2,120 |        103 |        262 |      2,485 |
| src                                                                                                                                     |          6 |      2,120 |        103 |        262 |      2,485 |
| src (Files)                                                                                                                             |          1 |         67 |          7 |          9 |         83 |
| src/cli                                                                                                                                 |          5 |      2,053 |         96 |        253 |      2,402 |
| src/cli/commands                                                                                                                        |          5 |      2,053 |         96 |        253 |      2,402 |
+-----------------------------------------------------------------------------------------------------------------------------------------+------------+------------+------------+------------+------------+

Files
+-----------------------------------------------------------------------------------------------------------------------------------------+----------+------------+------------+------------+------------+
| filename                                                                                                                                | language | code       | comment    | blank      | total      |
+-----------------------------------------------------------------------------------------------------------------------------------------+----------+------------+------------+------------+------------+
| /home/krzysztof/Documents/ELECTRONICS/universal_interface_adapter_board/universal_interface_adapter/firmware/src/cli/commands/analog.rs | Rust     |        476 |         27 |         61 |        564 |
| /home/krzysztof/Documents/ELECTRONICS/universal_interface_adapter_board/universal_interface_adapter/firmware/src/cli/commands/can.rs    | Rust     |        485 |         26 |         65 |        576 |
| /home/krzysztof/Documents/ELECTRONICS/universal_interface_adapter_board/universal_interface_adapter/firmware/src/cli/commands/i2c.rs    | Rust     |        447 |         16 |         51 |        514 |
| /home/krzysztof/Documents/ELECTRONICS/universal_interface_adapter_board/universal_interface_adapter/firmware/src/cli/commands/mod.rs    | Rust     |         25 |          0 |          4 |         29 |
| /home/krzysztof/Documents/ELECTRONICS/universal_interface_adapter_board/universal_interface_adapter/firmware/src/cli/commands/spi.rs    | Rust     |        620 |         27 |         72 |        719 |
| /home/krzysztof/Documents/ELECTRONICS/universal_interface_adapter_board/universal_interface_adapter/firmware/src/main.rs                | Rust     |         67 |          7 |          9 |         83 |
| Total                                                                                                                                   |          |      2,120 |        103 |        262 |      2,485 |
+-----------------------------------------------------------------------------------------------------------------------------------------+----------+------------+------------+------------+------------+

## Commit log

2025-09-06 added pdf schematic
2025-09-06 update pcb
    [bom.csv, designators.csv, positions.csv]
2026-02-19 Added LED module to firmware
2026-03-23 fixed serial send
    [GPIO.kicad_sch, analog.kicad_sch, bom.csv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]
2026-03-25 added uart.rx
2026-03-25 fixed uart file
2026-03-26 Added the analog.rs, but did not finish adding the analog format command for chanign from raw to mv values
    [diff.csv, diff.txt, results.csv]
2026-03-27 added i2c.rs file
2026-03-27 added spi.rs
2026-10-17 Fixed rs232, rs422, uart baud, parity, stop bit change. Added CR command to RS232.
